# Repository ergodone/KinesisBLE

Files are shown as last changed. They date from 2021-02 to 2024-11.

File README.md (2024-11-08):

# Wireless Kinesis Advantage BLE (Bluetooth Low Energy)

Turns the [Kinesis Advantage Keyboard](https://www.kinesis-ergo.com/shop/advantage2/) keyboard into a wireless BLE keyboard with a few extra features. Built with Adafruit's nRF52 Feather Express Arduino boards.

# About this fork

Adds support for the Kinesis Advantage or Professional keyboard to the original KinesisBLE design.  Also makes the PCB slightly smaller which should help minimize cost (specifically for JCLPCB).  The redesign has been done in open-source and free Kicad which should help future development.

# Firmware

The firmware in this repository it not what you want to use.  It's mikewudev's original firmware and is limited compared to ZMK.  

See the [ergodone ZMK repository](https://github.com/ergodone/zmk) for the ZMK firmware. Note there is a more current (and much preferred) ZMK firmware module that supports ZMK studio [ZMK-kinesis repository](https://github.com/ergodone/zmk-kinesis) and builds through GitHub actions (no need to install a build environment). This module is still in actively being worked on (as of 2024-11-08).

# A note on Function Keys

The original function keys are not particularly reliable nor responsive.  A PCB designed to use mechanical switches is documented here: **[Bluelightning32 Function Key Replacement](https://github.com/bluelightning32/kinesis-fn)**  This is not required for the KinesisBLE project but is a worthwhile upgrade if you are doing modifications.

# Wireless Kinesis Advantage BLE (Bluetooth Low Energy)

Turns the [Kinesis Advantage Keyboard](https://www.kinesis-ergo.com/shop/advantage2/) keyboard into a wireless BLE keyboard with a few extra features. Built with Adafruit's nRF52 Feather Express Arduino boards.

For instructions, see the **[wiki](https://github.com/sysdevmike/KinesisBLE/wiki)**. For more details on the build check out the **[project](https://hackaday.io/project/161578-wireless-ble-kinesis-advantage-custom-controller)**.

## Many thanks to

- [Yin Zhong](https://summivox.wordpress.com/2016/06/03/keyboard-matrix-scanning-and-debouncing/) - Explains a better way to handle debouncing.
- [Stapelberg](https://michael.stapelberg.ch/posts/2018-04-17-kinx-keyboard-controller/) - Double mention as I ported his debouncing used in his KinX controller to Matt's firmware.
- [Matt Vilim](https://github.com/mattvilim/FeatherCtrl) - New firmware is a fork of his FeatherCtrl project.
- [Adafruit](https://www.adafruit.com/product/3406) - Great documentation, libs and support.
- [afriggeri](https://github.com/afriggeri/kb) - The original firmware borrowed heavily from his [Blanck Keyboard](https://medium.com/@friggeri/the-blanck-keyboard-24afe12e81a) project.
- [Stapelberg](https://michael.stapelberg.de/posts/2013-03-21-kinesis_custom_controller/) - Michael Stapelberg's custom controller inspired this project. His PCB routing was inspirational.
- [Humble Hacker](http://humblehacker.com/blog/20100720/hacking-the-kinesis-contoured-keyboard/) - Detailed write-up helped me understand the keyboard matrix.
- [PCBgogo](http://www.pcbgogo.com) - All the boards were made by these guys. Fast turn-around.

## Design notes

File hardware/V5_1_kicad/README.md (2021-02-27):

# KinesisBLE with Kinesis Professional/Advantage compatible PCB

These are KiCad files for the KinesisBLE PCB.  The PCB has been made slightly smaller from mikewudev's original design while still maintaining the same connector locations. There is also the option of using the PCB in a Kinesis Professional (with the flex PCB "fingers") by using Molex 39-53-2134 on J2 and J7.  For Kinesis Advantage a Molex 39-53-2135 or Cvilux CF01-13-1V00 is used on J5 and J6.

A couple issues with the layout:
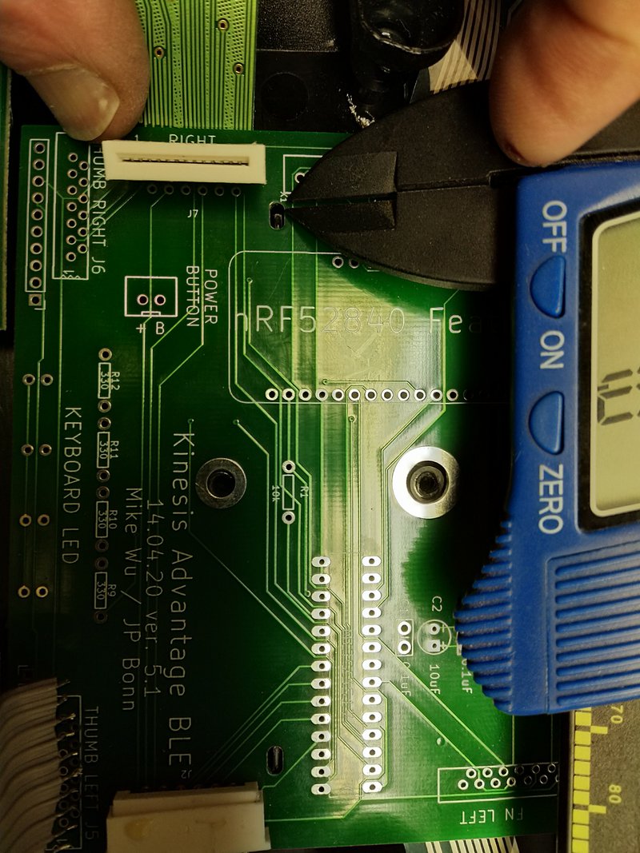
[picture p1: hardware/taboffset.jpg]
Image of offset
1) the slots for the tabs need to extend 1mm closer to the center of the board.  
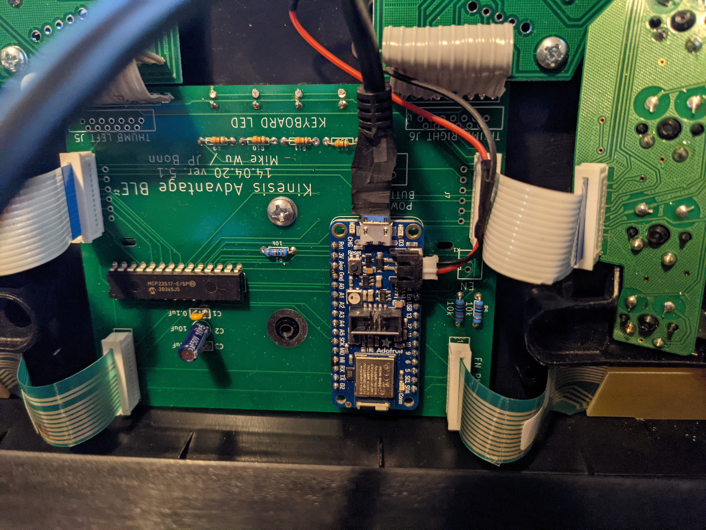
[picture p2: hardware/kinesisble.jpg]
Image of usb cable covering power button led
2) if you use a jumper for the power button led it may interfere with the usb plug. 
3) the usb cable connector may need to be trimmed down to avoid touching the bottom half of the case (see the image above).

The board has been tested and is currently in use using ZMK firmware.

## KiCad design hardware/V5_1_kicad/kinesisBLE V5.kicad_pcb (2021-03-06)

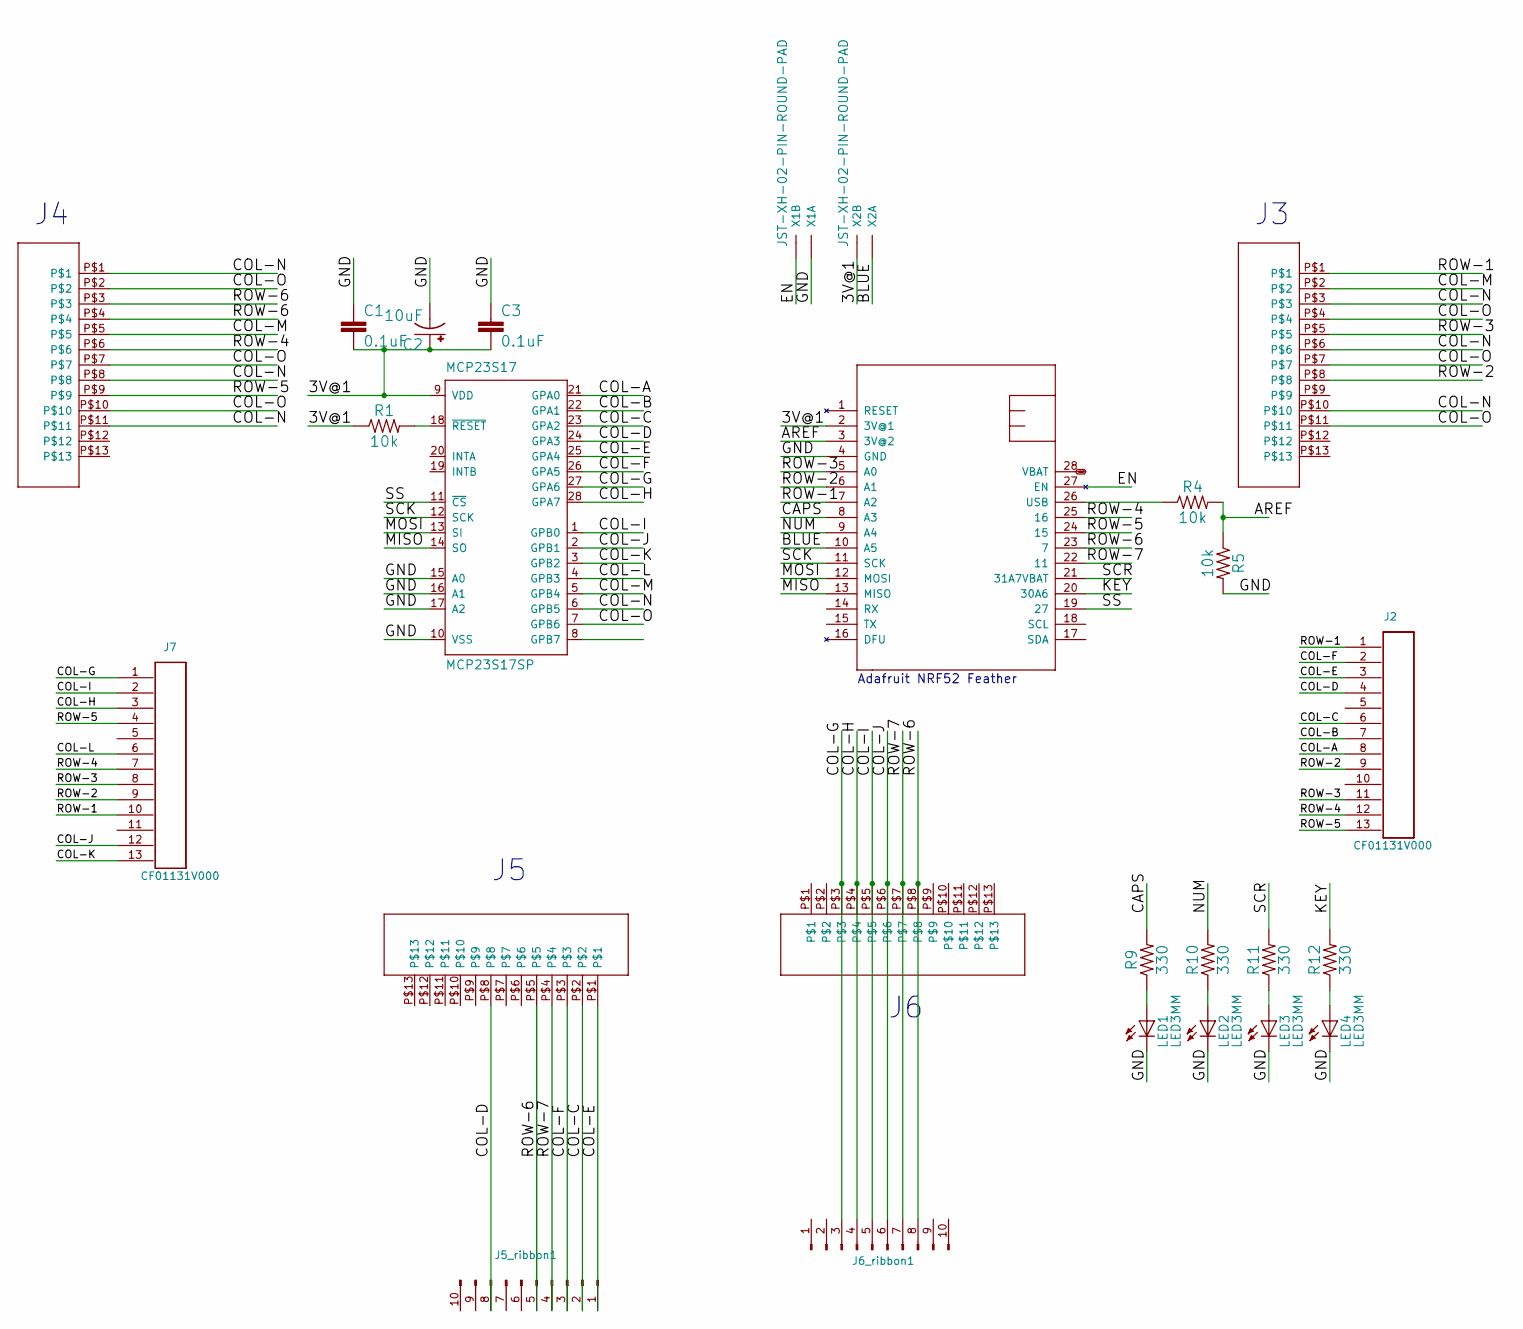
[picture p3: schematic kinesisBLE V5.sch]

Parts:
C1, C3: 0.1uF; CAP-PTH-SMALL-KIT
C2: 10uF; CPOL-RADIAL-2.5MM-5MM
J2, J7: CF01131V000; molex 39-53-2134
J5_ribbon1, J6_ribbon1: PinHeader_1x10_P2.54mm; PinHeader_1x10_P2.54mm_Vertical
LED1, LED2, LED3, LED4: LED3MM
MCP23S17: MCP23S17SP; DIL28-3
R1, R4, R5: 10k; AXIAL-0.3
R9, R10, R11, R12: 330; AXIAL-0.3
U$1: NRF52FEATHER
U$2, U$3, U$6, U$7: Cvilux CF01131V000; TOPLINKS_STAPELBERG
X1, X2: JST-XH-02-PIN-ROUND-PAD; JST-XH-02-PACKAGE-ROUND-PAD

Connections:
/3V@1: C1.2, C2.1 (+), C3.2, MCP23S17.9 (VDD), R1.P$1 (1), U$1.2 (3V@1), X2.1
/AREF: R4.P$2 (2), R5.P$1 (1), U$1.3 (3V@2)
/BLUE: U$1.10 (A5), X2.2
/CAPS: R9.P$2 (2), U$1.8 (A3)
/COL-A: J2.8, MCP23S17.21 (GPA0)
/COL-B: J2.7, MCP23S17.22 (GPA1)
/COL-C: J2.6, J5_ribbon1.2, MCP23S17.23 (GPA2), U$6.P$2
/COL-D: J2.4, J5_ribbon1.8, MCP23S17.24 (GPA3), U$6.P$8
/COL-E: J2.3, J5_ribbon1.1, MCP23S17.25 (GPA4), U$6.P$1
/COL-F: J2.2, J5_ribbon1.3, MCP23S17.26 (GPA5), U$6.P$3
/COL-G: J6_ribbon1.3, J7.1, MCP23S17.27 (GPA6), U$7.P$3
/COL-H: J6_ribbon1.4, J7.3, MCP23S17.28 (GPA7), U$7.P$4
/COL-I: J6_ribbon1.5, J7.2, MCP23S17.1 (GPB0), U$7.P$5
/COL-J: J6_ribbon1.6, J7.12, MCP23S17.2 (GPB1), U$7.P$6
/COL-K: J7.13, MCP23S17.3 (GPB2)
/COL-L: J7.6, MCP23S17.4 (GPB3)
/COL-M: MCP23S17.5 (GPB4), U$2.P$5, U$3.P$2
/COL-N: MCP23S17.6 (GPB5), U$2.P$1, U$2.P$8, U$2.P$11, U$3.P$3, U$3.P$6, U$3.P$10
/COL-O: MCP23S17.7 (GPB6), U$2.P$2, U$2.P$7, U$2.P$10, U$3.P$4, U$3.P$7, U$3.P$11
/EN: U$1.27 (EN), X1.1
/GND: C1.1, C2.2 (-), C3.1, LED1.K (C), LED2.K (C), LED3.K (C), LED4.K (C), MCP23S17.10 (VSS), MCP23S17.15 (A0), MCP23S17.16 (A1), MCP23S17.17 (A2), R5.P$2 (2), U$1.4 (GND), X1.2
/KEY: R12.P$2 (2), U$1.20 (30A6)
/MISO: MCP23S17.14 (SO), U$1.13 (MISO)
/MOSI: MCP23S17.13 (SI), U$1.12 (MOSI)
/NUM: R10.P$2 (2), U$1.9 (A4)
/ROW-1: J2.1, J7.10, U$1.7 (A2), U$3.P$1
/ROW-2: J2.9, J7.9, U$1.6 (A1), U$3.P$8
/ROW-3: J2.11, J7.8, U$1.5 (A0), U$3.P$5
/ROW-4: J2.12, J7.7, U$1.25 (16), U$2.P$6
/ROW-5: J2.13, J7.4, U$1.24 (15), U$2.P$9
/ROW-6: J5_ribbon1.5, J6_ribbon1.8, U$1.23 (7), U$2.P$3, U$2.P$4, U$6.P$5, U$7.P$8
/ROW-7: J5_ribbon1.4, J6_ribbon1.7, U$1.22 (11), U$6.P$4, U$7.P$7
/SCK: MCP23S17.12 (SCK), U$1.11 (SCK)
/SCR: R11.P$2 (2), U$1.21 (31A7VBAT)
/SS: MCP23S17.11 (~CS), U$1.19 (27)
unnamed: LED1.A, R9.P$1 (1)
unnamed: LED2.A, R10.P$1 (1)
unnamed: LED3.A, R11.P$1 (1)
unnamed: LED4.A, R12.P$1 (1)
unnamed: MCP23S17.18 (~RESET), R1.P$2 (2)
unnamed: R4.P$1 (1), U$1.26 (USB)
VBAT: U$1.28 (VBAT)

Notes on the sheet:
Adafruit NRF52 Feather

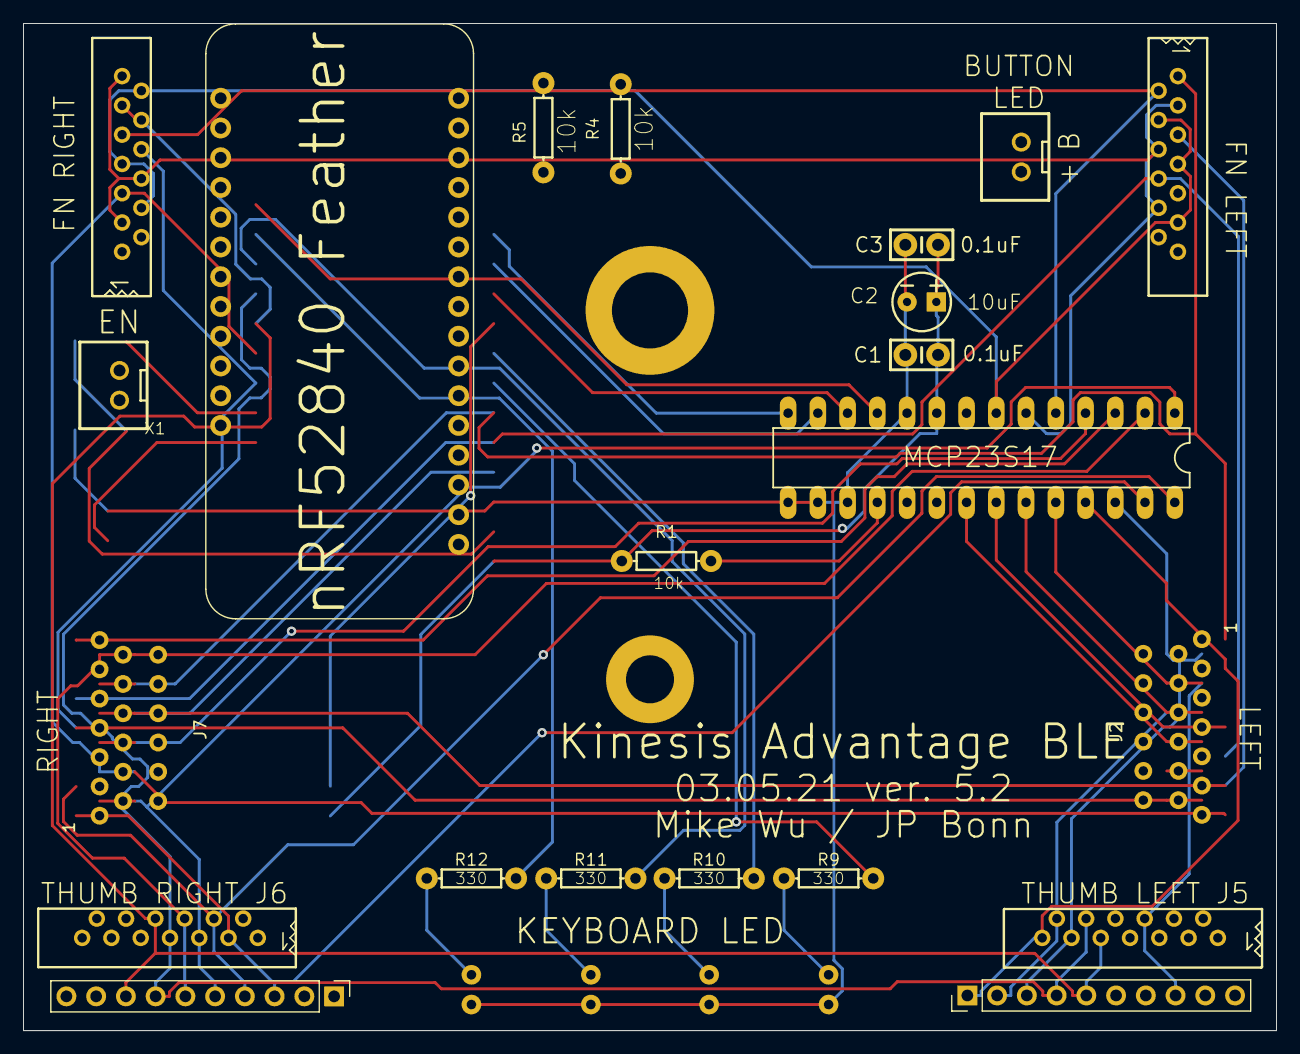
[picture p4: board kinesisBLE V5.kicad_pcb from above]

Board: 2 copper layers, 107.0 x 86.0 mm, 30 parts (0 on the bottom side), 41 nets.

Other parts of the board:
Hole1: MountingHole_6.5mm_M6_DIN965_Pad; MountingHole_6.4mm_M6_DIN965_Pad
align1, align2: alignment kinesis
hole2: MountingHole_4.3mm_M4_DIN965_Pad

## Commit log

2020-04-27 Kicad/Kinesis Professional version.
    [kinesisBLE V5.dsn, kinesisBLE V5.kicad_pcb, kinesisBLE V5.sch]
2021-02-27 added pictures of board
2021-03-06 corrected physical layout
    [kinesisBLE V5.dsn, kinesisBLE V5.kicad_pcb]
